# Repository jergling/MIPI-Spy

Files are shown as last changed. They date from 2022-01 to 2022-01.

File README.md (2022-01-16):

# MIPI Spy
 Hardware tools for non-invasively sniffing MIPI D-Phy links. 
MiPiSpyBoard

In order to contribute useful data to the OpenHD project, I designed a simple PCB that splices two 15-pin MIPI FFCs end-to-end, to allow non-invasive, man-in-the-middle sniffing of the data. This serves several purposes:

## Non-destructive and low-risk probing of the I2C bus
No more risk of shorting or ripping pads by clipping onto the FPC connector
## Latency benchmarking
Sensor ICs incorporate buffering stages between pixel capture and ISP. By probing the data lanes and a strobing light source, one can measure how long the module takes to process each pixel/line/stripe/field/frame as the delay between the strobe pulse and the first transmission of "bright" bytes on a data lane. This will help determine which modules are best suited to our low-latency application.
## Accurate probing of sLVDS
Due to the sensitivity of LVDS to impedence changes and phase, the length and impedence-matched routing on the MIPI Spy presents the best possible scenario for observing the signal with minimual harm to the transmission quality. Ideally, this means 0 extra retransmissions incurred due to instrumentation. Compared to scratching the coating off of an FFC and soldering on leads, this is a major step up.

# Hardware

## Pi version (v1.0)
- 15-FFC (1.0mm pitch) to 15-FFC (1.0mm pitch) F/F with 15-pin breakout header (2.54 mm pitch)
- Requires 15-wire MIPI camera, 2 flex cables (one top-bottom, one top-top), and a host machine with support for the camera module
- Awaiting validation samples

## DJI-A version (*not done*)
- Hirose DF56-26P to DF56-26P with 26-pin breakout header
- Requires 2 DJI or Caddx FPV camera cables, a DJI FPV compatible camera, and a DJI or compatible air unit
- May not be possible due to unavailability of DF56-26S connectors

## DJI-B version (*not done*)
- Hirose DF36-30P to DF36-30P with 30-pin breakout header
- Requires 2 custom DF56-to-DF36 cables, a DJI FPV compatible camera, and a DJI or compatible air unit
- Alternative to DJI-A in case of sourcing issues
- Higher cost due to custom cable requirement

## HDZero Version (*not done*)
- Hirose DF36-20P to DF36-20P with 20-pin breakout header
- Requires 2 HDzero "Mipi" cables, an HDZero camera, and an HDZero VTX
- According to sources, this is actually a DVP link, not MIPI

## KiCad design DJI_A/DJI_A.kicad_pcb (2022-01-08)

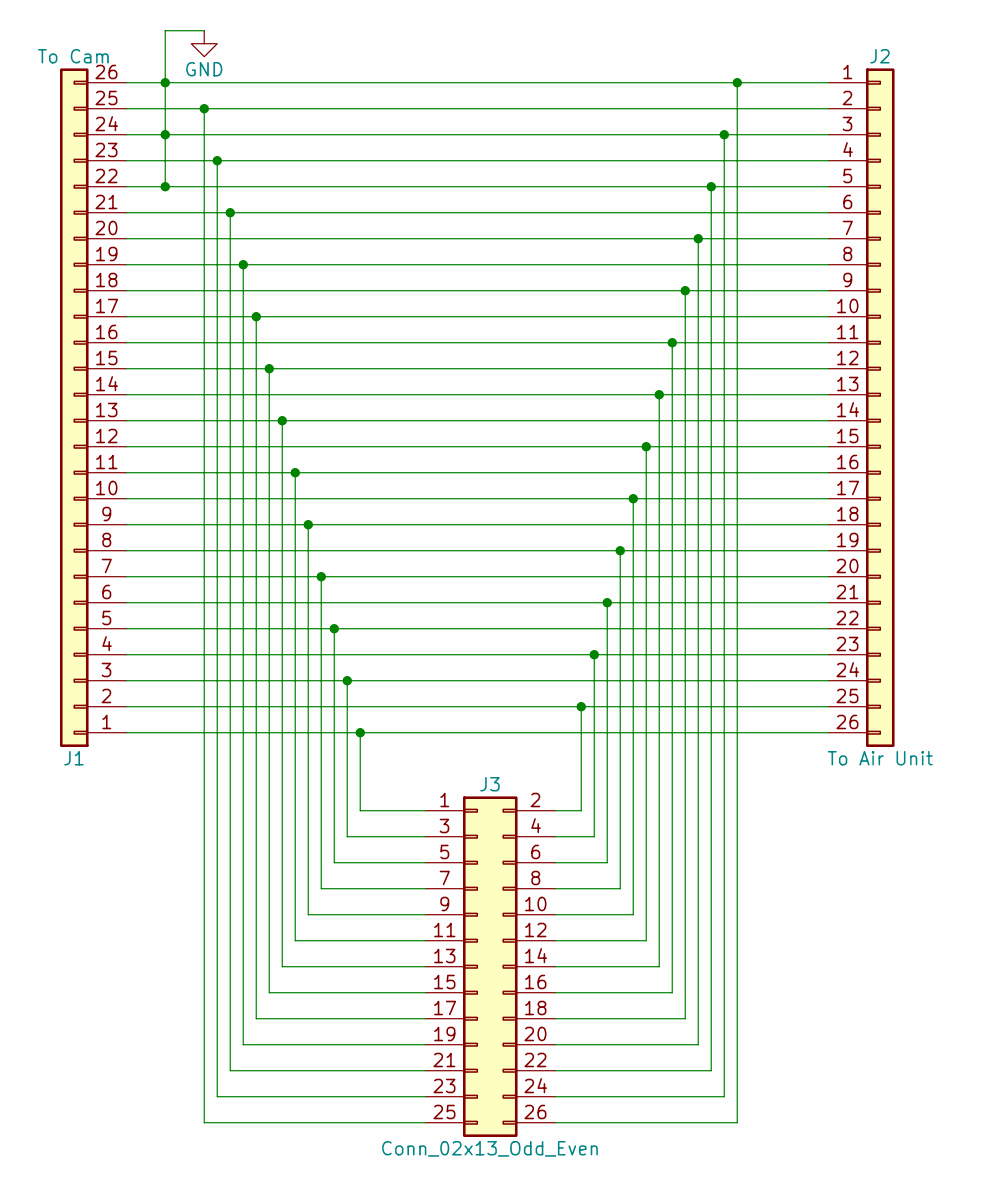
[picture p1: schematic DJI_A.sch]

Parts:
J1: To Cam; DF56C-26S
J2: To Air Unit; DF56C-26S
J3: Conn_02x13_Odd_Even; PinHeader_2x13_P2.54mm_Vertical

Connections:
GND: J1.22, J1.24, J1.26, J1.GND, J2.1, J2.3, J2.5, J2.GND, J3.22, J3.24, J3.26
unnamed: J1.1, J2.26, J3.1
unnamed: J1.2, J2.25, J3.2
unnamed: J1.3, J2.24, J3.3
unnamed: J1.4, J2.23, J3.4
unnamed: J1.5, J2.22, J3.5
unnamed: J1.6, J2.21, J3.6
unnamed: J1.7, J2.20, J3.7
unnamed: J1.8, J2.19, J3.8
unnamed: J1.9, J2.18, J3.9
unnamed: J1.10, J2.17, J3.10
unnamed: J1.11, J2.16, J3.11
unnamed: J1.12, J2.15, J3.12
unnamed: J1.13, J2.14, J3.13
unnamed: J1.14, J2.13, J3.14
unnamed: J1.15, J2.12, J3.15
unnamed: J1.16, J2.11, J3.16
unnamed: J1.17, J2.10, J3.17
unnamed: J1.18, J2.9, J3.18
unnamed: J1.19, J2.8, J3.19
unnamed: J1.20, J2.7, J3.20
unnamed: J1.21, J2.6, J3.21
unnamed: J1.23, J2.4, J3.23
unnamed: J1.25, J2.2, J3.25

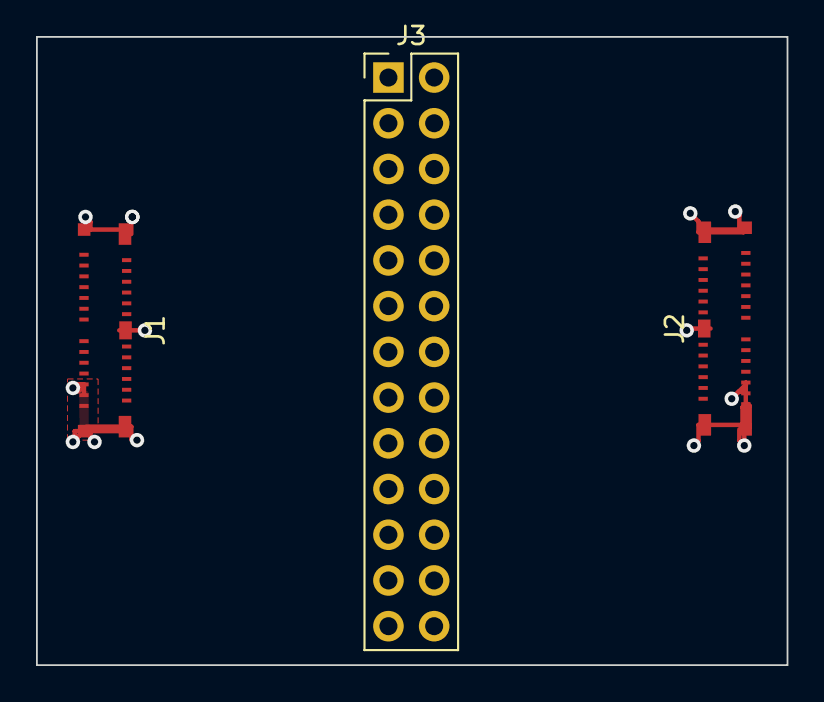
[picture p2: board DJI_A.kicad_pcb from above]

Board: 2 copper layers, 41.7 x 34.9 mm, 3 parts (0 on the bottom side), 24 nets.

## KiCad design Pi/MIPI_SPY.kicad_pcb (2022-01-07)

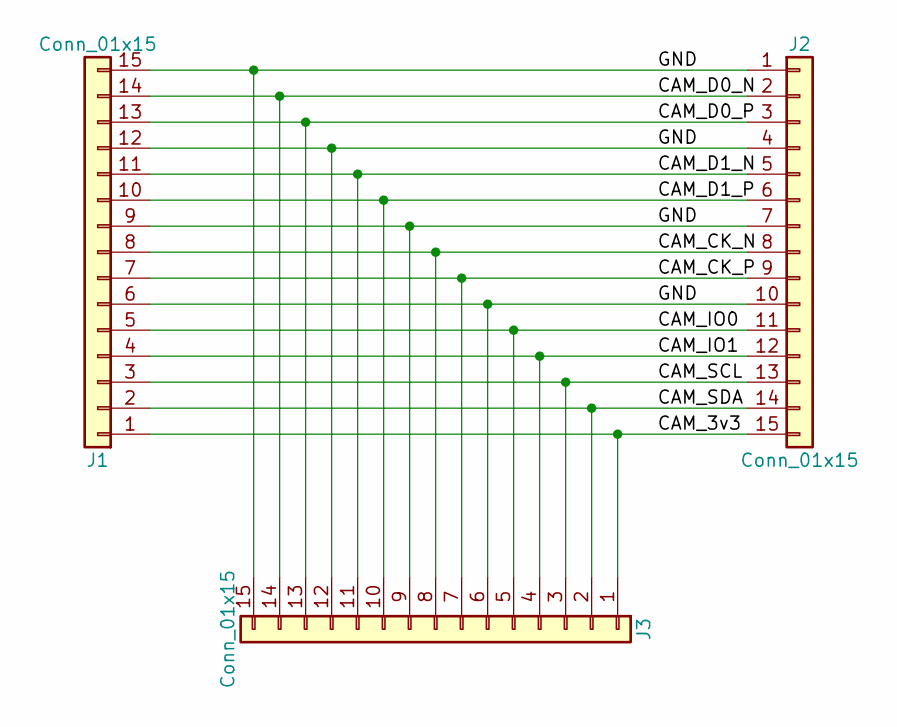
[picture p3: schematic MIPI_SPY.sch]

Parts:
J1, J2: Conn_01x15; TE_1-84952-5_1x15-1MP_P1.0mm_Horizontal
J3: Conn_01x15; PinHeader_1x15_P2.54mm_Vertical

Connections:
/CAM_3v3: J1.1, J2.15, J3.1
/CAM_CK_N: J1.8, J2.8, J3.8
/CAM_CK_P: J1.7, J2.9, J3.7
/CAM_D0_N: J1.14, J2.2, J3.14
/CAM_D0_P: J1.13, J2.3, J3.13
/CAM_D1_N: J1.11, J2.5, J3.11
/CAM_D1_P: J1.10, J2.6, J3.10
/CAM_IO0: J1.5, J2.11, J3.5
/CAM_IO1: J1.4, J2.12, J3.4
/CAM_SCL: J1.3, J2.13, J3.3
/CAM_SDA: J1.2, J2.14, J3.2
/GND: J1.6, J1.9, J1.12, J1.15, J2.1, J2.4, J2.7, J2.10, J3.6, J3.9, J3.12, J3.15

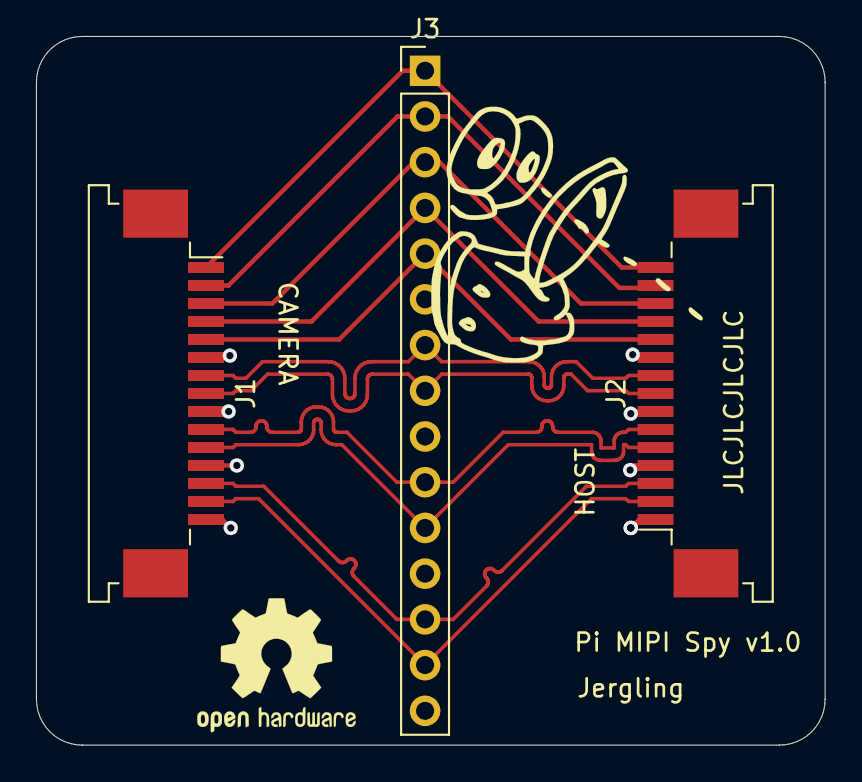
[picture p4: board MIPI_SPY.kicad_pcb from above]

Board: 2 copper layers, 43.8 x 39.4 mm, 3 parts (0 on the bottom side), 12 nets.

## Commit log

2022-01-07 Initial Commit
    Committing all ECAD for the v1.0 to the repo.
    [MIPI_SPY-B_Cu.gbl, MIPI_SPY-B_Mask.gbs, MIPI_SPY-B_Paste.gbp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]
2022-01-07 Added image of board
2022-01-08 Subdivided by target, added DJI_A dir
    [DJI_A.kicad_pcb, DJI_A.sch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]
2022-01-08 Unrouted DJI_A PCB added
2022-01-08 Possible straight-through pinout. Don't use this version.
    [DJI_A.kicad_pcb, DJI_A.sch]
